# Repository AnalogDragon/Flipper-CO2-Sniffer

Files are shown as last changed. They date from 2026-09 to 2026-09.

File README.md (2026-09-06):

[简体中文](README-zh.md)

# CO2 Sniffer

CO2 Sniffer is a BMP388 + SCD30 environmental monitor for the Flipper Zero. Plug
the board into the GPIO header and open the app to view CO2, temperature,
humidity, pressure and estimated altitude. Readings can also be saved to the
microSD card or sent to a computer over USB.
The software project in `SW/` was developed by OpenAI Codex.

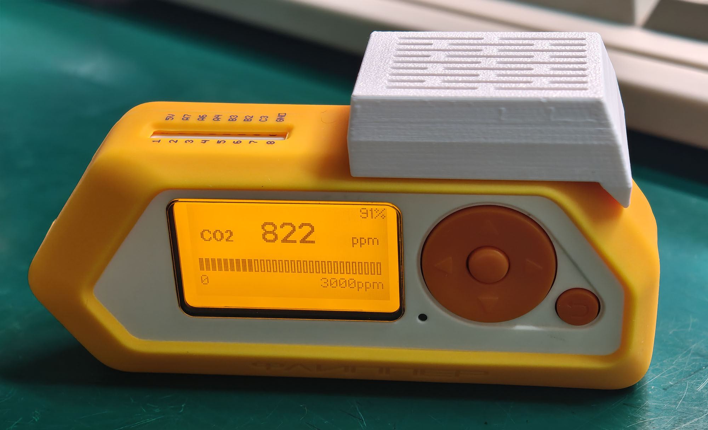
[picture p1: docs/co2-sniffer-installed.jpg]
CO2 Sniffer running on a Flipper Zero


## Main features

- Measures CO2, temperature, humidity and pressure, and estimates altitude from
  the pressure reading.
- Offers several live dashboard layouts and history graphs for all five values.
- Saves readings to CSV at a chosen interval and duration, or sends them to a
  computer over USB.
- Continues with the remaining sensor if one becomes unavailable and reconnects
  it automatically when possible.

To keep startup transients out of the trend, history graphs omit the first 10
seconds after the app starts or the SCD30 reconnects.

## Controls

Button functions change with the current screen. All actions below are short
presses unless marked as a hold.

| Current screen | Input | Function |
| --- | ----- | --- |
| Dashboard | **LEFT** | Open **Data Recording** |
| Dashboard | **RIGHT** | Open the first history graph |
| History graph | **LEFT / RIGHT** | Show the previous / next graph; return to the dashboard at either end |
| Dashboard | **UP / DOWN** | Change the dashboard layout |
| History graph | **UP / DOWN** | Change the graph time scale |
| Dashboard / history graph | **BACK** | Open the clear-history prompt; press **OK** to clear or **BACK** to cancel |
| Data Recording | **UP / DOWN** | Select the interval, length or **Start** field |
| Data Recording | **OK** | Change the selected setting; start when **Start** is selected, or stop while recording |
| Changing a recording setting | **LEFT / RIGHT** | Choose the required value |
| Changing a recording setting / Data Recording | **BACK** | Finish the current change; when not changing a setting, return to the dashboard |
| SCD30 settings | **UP / DOWN**, **OK** | Choose a setting and change it, or open manual calibration |
| Manual-calibration input | **LEFT / RIGHT**, **UP / DOWN** | Select and adjust a digit; press **OK** to review the value |

The following functions require a button hold:

| Where | Input | Function |
| ----- | ----- | --- |
| Data Recording, while not changing a setting | Hold **LEFT** for 2 seconds | Open SCD30 settings |
| While reviewing a manual-calibration value | Hold **OK** for 2 seconds | Start calibration after the progress bar completes |
| When no calibration or exit prompt is shown | Hold **OK** | Turn the always-on backlight on or off |
| Any page | Hold **BACK** | Open the exit prompt; press **OK** to exit or **BACK** to cancel |

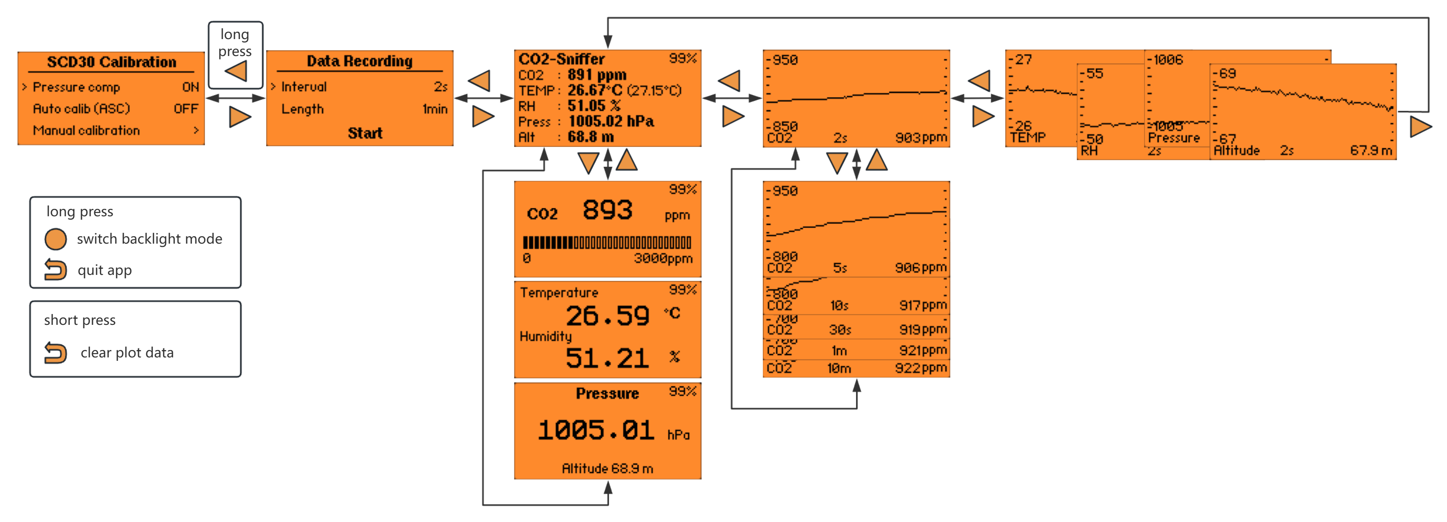
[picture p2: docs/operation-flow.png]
CO2 Sniffer page navigation and controls flowchart


## Data recording

Data recording is useful for tracking environmental changes over time. Press
**LEFT** from the dashboard to open **Data Recording**, choose the interval and
recording length, then select **Start**. Recording ends automatically at the
chosen time. For a continuous recording, or to stop early, press **OK**.

| Setting | Choices |
| --- | --- |
| Interval | 2 s, 5 s, 10 s, 30 s, 1 min |
| Length | 1 min, 5 min, 10 min, 30 min, 1 h, 2 h, 8 h, 24 h, continuous |

Files are saved in `/ext/co2_sniffer/` on the microSD card. Each filename
includes the start time, interval and recording length. Every row contains the
time, elapsed recording time and available sensor readings; values from a
temporarily unavailable sensor are left empty. A blinking `REC` badge means
recording is active. If `SD!` appears, check that the microSD card is available
and writable.

## SCD30 settings and calibration

From **Data Recording**, hold **LEFT** for 2 seconds to open **SCD30
Calibration**. It provides two everyday settings:

- **Pressure comp** uses the current pressure measured by the BMP388 to improve
  SCD30 measurement accuracy.
- **Auto calib (ASC)** lets the SCD30 adjust its baseline during long-term use.

Pressure compensation is on and ASC is off by default. The app remembers later
changes and uses them again at the next startup.

### Manual calibration

Manual calibration is recommended only when the reading has a clear offset and
a reliable CO2 reference concentration is available. Do not treat outdoor air
as an exact 400 ppm reference.

Before calibration, leave the sensor running in a stable reference environment
for at least two minutes and keep faces away from it. Select **Manual
calibration**, enter the actual reference concentration (`0400–2000 ppm`), and
press **OK** to review it. Hold **OK** for 2 seconds; calibration starts only
after the progress bar completes, using the value entered as its reference.

## Hardware

The board connects to the Flipper GPIO port through a 2.54 mm 1×10 pin header
and carries the following sensors:

| Device | Role | I2C address |
| --- | ---- | --- |
| Sensirion SCD30 | CO2, temperature, humidity | 0x61 |
| Bosch BMP388 | temperature, pressure | 0x76 |

I2C runs on GPIO C0 (SCL) / C1 (SDA), and the board is powered from the
Flipper's 3V3/5V pins. KiCad schematic and PCB design sources are in `HW/`.

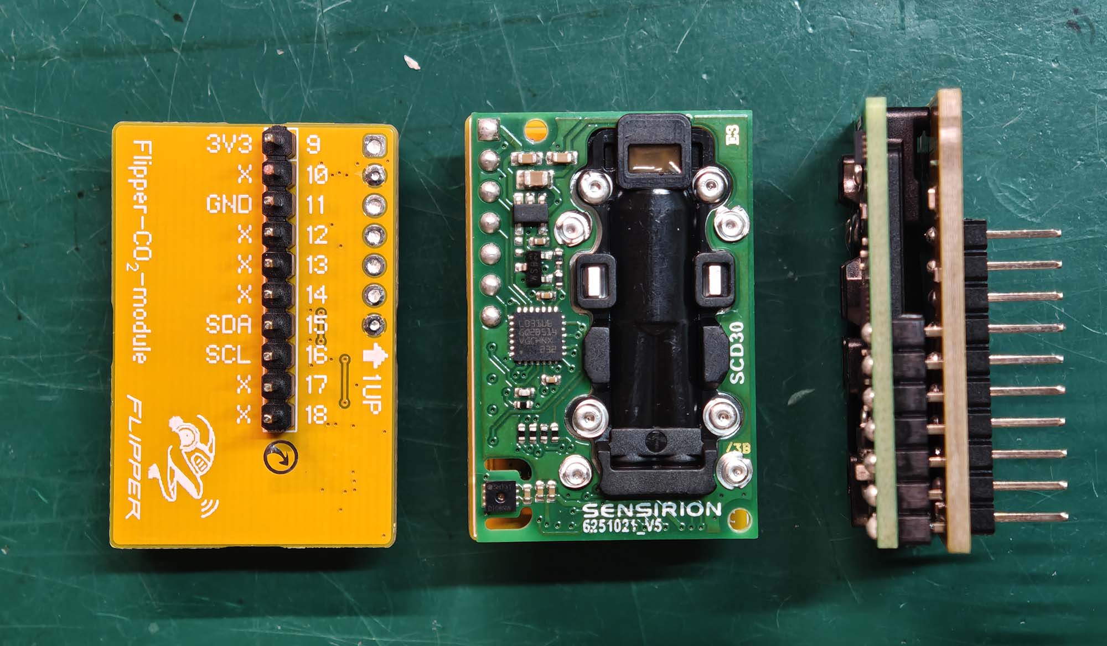
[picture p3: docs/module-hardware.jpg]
CO2 Sniffer module hardware


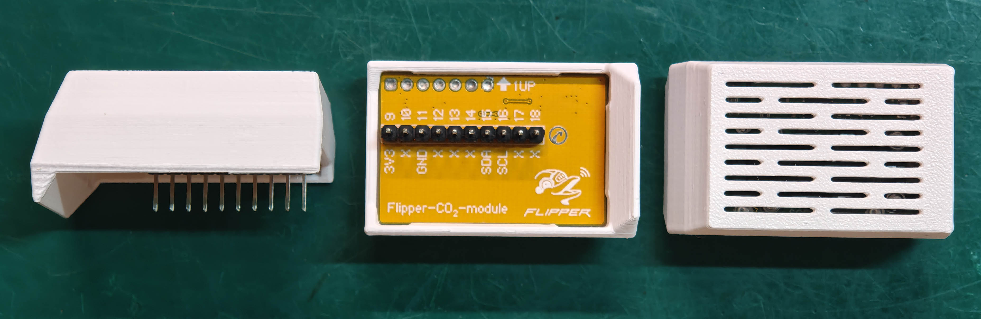
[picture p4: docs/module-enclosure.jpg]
CO2 Sniffer module enclosure from multiple angles


## Fault handling

If one sensor is temporarily disconnected, its readings are shown as
unavailable while the other sensor continues to work. The app attempts to
restore the connection automatically. If the screen reports that the I2C bus
cannot be recovered, exit the app and restart the Flipper as instructed.

## Layout

- `HW/` — KiCad schematic and PCB design sources.
- `SW/` — Flipper app sources.
- `3d/` — Printable enclosure files: a 3MF with Bambu Lab settings and the original STEP model.
- `PROTOCOL.md` — full USB CDC serial protocol documentation.
- `README-zh.md` — this document in Chinese.

## License

GPL-3.0, see [LICENSE](LICENSE).

## USB data output

To receive live readings on a computer, connect the Flipper over USB and select
the second virtual COM port detected by the system. The first port is reserved
for the Flipper CLI. Measurements use a binary frame format; see
**[PROTOCOL.md](PROTOCOL.md)** for the complete frame format and parsing details.

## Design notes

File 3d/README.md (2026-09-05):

[简体中文](README-zh.md)

# 3D Enclosure

These are the printable 3D enclosure files. `shell01.3mf` includes Bambu Lab print settings, while `shell02.STEP` is the original model.

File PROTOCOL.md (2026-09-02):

[简体中文](PROTOCOL-zh.md)

# CO2 Sniffer — USB CDC Serial Protocol

The Flipper app (`SW/co2_sniffer.c`) reads the SCD30 (CO2, temperature, humidity)
and BMP388 (temperature, pressure) sensors and streams a framed binary report to a
PC over USB CDC (virtual COM port). This document describes that stream.

## 1. Transport

- **USB mode:** the app switches the Flipper to the dual CDC configuration
  (`usb_cdc_dual`) and transmits on **interface 1** — on the PC this is the
  **second** virtual COM port. The first COM port is the Flipper CLI console.
- **Baud rate:** irrelevant. CDC is a virtual serial port; the Flipper sends
  at full USB speed and the host-side baud setting is ignored.
- **Flow control:** none. `furi_hal_cdc_send` is non-blocking — if the endpoint
  is busy (host not reading fast enough) the frame is **silently dropped**.
  There is no retry, no buffering beyond the USB endpoint.
- **Host-open detection:** the app treats the port as "open" when DTR is
  asserted (shown as `USB:TX` on the screen; `USB:wait` means no host).
- **Rate:** one frame every **333 ms** (`CO2_TICK_MS`), continuously, for as
  long as the app runs.
- **On exit** the app restores the USB mode that was active before it started.

## 2. Frame format

Every frame is **19 bytes**, big-endian payload, CRC appended little-endian:

| Offset | Size | Field | Encoding |
| --- | ---- | ----- | --- |
| 0 | 4 | Header | `DE AD FF 09` (CH552 VID `0xDEAD` + PID `0xFF09`) |
| 4 | 1 | Payload length | Always `0x0C` (12) |
| 5 | 2 | CO2 (SCD30) | uint16, **ppm**, big-endian |
| 7 | 2 | Temperature (SCD30) | int16, **°C × 100**, big-endian |
| 9 | 2 | Humidity (SCD30) | uint16, **%RH × 100**, big-endian |
| 11 | 2 | Temperature (BMP388) | int16, **°C × 100**, big-endian |
| 13 | 4 | Pressure (BMP388) | uint32, **Pa**, big-endian |
| 17 | 2 | CRC16 | Modbus CRC over bytes 0..16, **little-endian** |

Total: 4 + 1 + 12 + 2 = 19 bytes.

Decoding:

```
co2_ppm     = uint16_be(payload[0:2])
t_scd_c     = int16_be(payload[2:4])  / 100.0
rh_scd_pct  = uint16_be(payload[4:6]) / 100.0
t_bmp_c     = int16_be(payload[6:8])  / 100.0
p_bmp_pa    = uint32_be(payload[8:12])
```

### Sensor failure sentinels

The app re-initializes a failing sensor on every tick and keeps streaming
regardless. A failed sensor reports its fields as all-`0xFF`:

- SCD30 failed → bytes 5..10 = `FF FF FF FF FF FF`
  (CO2 `0xFFFF`, temperature `0xFFFF`, humidity `0xFFFF`)
- BMP388 failed → bytes 11..16 = `FF FF FF FF FF FF`
  (temperature `0xFFFF`, pressure `0xFFFFFFFF`)

Treat these as **"sensor error"**, not as values: `0xFFFF` temperature would
otherwise decode as −0.01 °C, `0xFFFF` humidity as 655.35 %RH.

## 3. CRC16

Modbus CRC16 over the first 17 bytes (header + length + payload):

- Polynomial: `0xA001` (reflected `0x8005`)
- Initial value: `0xFFFF`, no final XOR
- LSB-first (reflected)
- Stored little-endian (low byte at offset 17, high byte at offset 18)

Reference implementations:

```c
/* Modbus CRC16: poly 0xA001, init 0xFFFF, LSB first */
uint16_t crc16_modbus(const uint8_t* data, size_t len) {
    uint16_t crc = 0xFFFF;
    for(size_t i = 0; i < len; i++) {
        crc ^= data[i];
        for(uint8_t b = 0; b < 8; b++)
            crc = (crc & 1) ? (crc >> 1) ^ 0xA001 : crc >> 1;
    }
    return crc;
}
```

```python
def crc16_modbus(data: bytes) -> int:
    crc = 0xFFFF
    for b in data:
        crc ^= b
        for _ in range(8):
            crc = (crc >> 1) ^ 0xA001 if crc & 1 else crc >> 1
    return crc
```

Check: `crc16_modbus(frame[:17])` must equal `frame[17] | frame[18] << 8`, and
`crc16_modbus(frame) == 0` for a complete valid frame.

## 4. Example frame

| Value | Encoding |
| ----- | --- |
| CO2 = 512 ppm | `02 00` |
| SCD30 T = 24.55 °C | `09 97` |
| SCD30 RH = 43.20 %RH | `10 E0` |
| BMP388 T = 24.62 °C | `09 9E` |
| BMP388 P = 100123 Pa | `00 01 87 1B` |

```
DE AD FF 09 0C 02 00 09 97 10 E0 09 9E 00 01 87 1B CA E0
└ header ┘ └len┘ └────────── payload (12) ──────────┘ └ CRC16 LE
```

CRC16 over bytes 0..16 = `0xE0CA`, stored little-endian as `CA E0`.

## 5. Parsing the stream

The stream is a continuous byte pipe with no idle marker. To synchronize:

1. Scan for the header `DE AD FF 09`.
2. Take the byte after the header as length; expect `0x0C`.
3. Take `1 + len + 2` more bytes and verify the CRC over `header + length + payload`
   (`crc16_modbus(frame[:17]) == crc_le`). Reject and rescan on mismatch.
4. An alternative is to chunk by 19 bytes once aligned — a valid CRC per chunk
   keeps the alignment honest.

Note that frames can be dropped by the Flipper when the host is not reading, so
a parser must never assume uninterrupted sequence numbers (there are none).

## 6. Sampling and update rates

The frame cadence (333 ms) is **faster** than the sensor update rates:

- **SCD30:** measurement interval is set to **2 s** at init, so CO2, SCD30
  temperature and humidity values change every ~2 s (every 6th frame) and
  repeat in between. ASC (automatic self-calibration) is disabled at init.
- **BMP388:** configured for 50 Hz output (OSR ×32/×32, normal mode) and is
  read on every 333 ms tick; its temperature/pressure are fresh in every frame.
- **Pressure compensation:** the app feeds the SCD30 an ambient pressure
  (mbar) derived from the BMP388 pressure low-pass filtered with
  `P_FIL = 0.95·P_FIL + 0.05·P_LIN`. When the filtered pressure changes and is
  within 700..1200 mbar, the SCD30 measurement is restarted with the new
  pressure. Rounding is `(uint16_t)((P_FIL + 0.5) / 100)`.
- **Re-init:** pressing **OK** on the Flipper re-initializes both sensors
  (soft reset; the original CH552 board power-cycled them instead).

## 7. History note

The original CH552 sniffer board streamed the same report layout as an HID
report. FAPs cannot register custom HID descriptors, so this port transmits
the identical frame over CDC. The layout is byte-compatible with the CH552 HID
report, which is why the header encodes the CH552's VID/PID.

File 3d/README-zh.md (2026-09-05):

[English](README.md)

# 3D 外壳

这里是可直接打印的 3D 外壳文件。`shell01.3mf` 包含拓竹打印配置，`shell02.STEP` 是原始模型文件。

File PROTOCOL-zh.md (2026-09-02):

[English](PROTOCOL.md)

# CO2 Sniffer — USB CDC 串口协议

Flipper 应用（`SW/co2_sniffer.c`）读取 SCD30（CO2、温度、湿度）与 BMP388
（温度、气压）传感器，并通过 USB CDC（虚拟串口）向 PC 流式发送二进制帧数据。
本文档描述这个数据流。

## 1. 传输层

- **USB 模式：**应用把 Flipper 切换到双 CDC 配置（`usb_cdc_dual`），并在
  **接口 1** 上发送数据——PC 上是**第二个**虚拟串口。第一个串口是 Flipper
  CLI 控制台。
- **波特率：**无意义。CDC 是虚拟串口；Flipper 以全速 USB 发送，上位机端设置
  的波特率会被忽略。
- **流控：**无。`furi_hal_cdc_send` 非阻塞——端点忙（上位机读取不及时）时该帧
  被**静默丢弃**。没有重传，也没有超出 USB 端点的缓冲。
- **主机打开检测：**当 DTR 置位时应用认为端口"已打开"（屏幕显示 `USB:TX`；
  `USB:wait` 表示没有主机）。
- **速率：**应用运行期间每 **333 ms**（`CO2_TICK_MS`）连续发送一帧。
- **退出时**应用恢复启动前的 USB 模式。

## 2. 帧格式

每帧 **19 字节**，载荷大端序，CRC 以小端序追加：

| 偏移 | 大小 | 字段 | 编码 |
| ---- | ---- | ---- | ---- |
| 0 | 4 | 帧头 | `DE AD FF 09`（CH552 VID `0xDEAD` + PID `0xFF09`） |
| 4 | 1 | 载荷长度 | 固定 `0x0C`（12） |
| 5 | 2 | CO2（SCD30） | uint16，**ppm**，大端序 |
| 7 | 2 | 温度（SCD30） | int16，**°C × 100**，大端序 |
| 9 | 2 | 湿度（SCD30） | uint16，**%RH × 100**，大端序 |
| 11 | 2 | 温度（BMP388） | int16，**°C × 100**，大端序 |
| 13 | 4 | 气压（BMP388） | uint32，**Pa**，大端序 |
| 17 | 2 | CRC16 | Modbus CRC，对字节 0..16 计算，**小端序** |

总计：4 + 1 + 12 + 2 = 19 字节。

解码公式：

```
co2_ppm     = uint16_be(payload[0:2])
t_scd_c     = int16_be(payload[2:4])  / 100.0
rh_scd_pct  = uint16_be(payload[4:6]) / 100.0
t_bmp_c     = int16_be(payload[6:8])  / 100.0
p_bmp_pa    = uint32_be(payload[8:12])
```

### 传感器故障哨兵值

应用每个周期都会重新初始化出故障的传感器，并保持数据流不断。故障传感器的
字段全部为 `0xFF`：

- SCD30 故障 → 字节 5..10 = `FF FF FF FF FF FF`
  （CO2 `0xFFFF`、温度 `0xFFFF`、湿度 `0xFFFF`）
- BMP388 故障 → 字节 11..16 = `FF FF FF FF FF FF`
  （温度 `0xFFFF`、气压 `0xFFFFFFFF`）

请把这些值当作**"传感器错误"**而不是数值：`0xFFFF` 温度会被解码为 −0.01 °C，
`0xFFFF` 湿度会被解码为 655.35 %RH。

## 3. CRC16

对前 17 个字节（帧头 + 长度 + 载荷）计算 Modbus CRC16：

- 多项式：`0xA001`（`0x8005` 的反射形式）
- 初值：`0xFFFF`，无最终异或
- LSB 优先（反射）
- 以小端序存储（低字节在偏移 17，高字节在偏移 18）

参考实现：

```c
/* Modbus CRC16: poly 0xA001, init 0xFFFF, LSB first */
uint16_t crc16_modbus(const uint8_t* data, size_t len) {
    uint16_t crc = 0xFFFF;
    for(size_t i = 0; i < len; i++) {
        crc ^= data[i];
        for(uint8_t b = 0; b < 8; b++)
            crc = (crc & 1) ? (crc >> 1) ^ 0xA001 : crc >> 1;
    }
    return crc;
}
```

```python
def crc16_modbus(data: bytes) -> int:
    crc = 0xFFFF
    for b in data:
        crc ^= b
        for _ in range(8):
            crc = (crc >> 1) ^ 0xA001 if crc & 1 else crc >> 1
    return crc
```

校验方法：`crc16_modbus(frame[:17])` 必须等于 `frame[17] | frame[18] << 8`，
且对完整有效帧 `crc16_modbus(frame) == 0`。

## 4. 示例帧

| 数值 | 编码 |
| ---- | ---- |
| CO2 = 512 ppm | `02 00` |
| SCD30 温度 = 24.55 °C | `09 97` |
| SCD30 湿度 = 43.20 %RH | `10 E0` |
| BMP388 温度 = 24.62 °C | `09 9E` |
| BMP388 气压 = 100123 Pa | `00 01 87 1B` |

```
DE AD FF 09 0C 02 00 09 97 10 E0 09 9E 00 01 87 1B CA E0
└ 帧头 ┘ └长度┘ └────────── 载荷 (12) ──────────┘ └ CRC16 LE
```

字节 0..16 的 CRC16 = `0xE0CA`，以小端序存储为 `CA E0`。

## 5. 解析数据流

数据流是连续的字节流，没有空闲标记。同步方法：

1. 扫描帧头 `DE AD FF 09`。
2. 帧头后的字节是长度；应为 `0x0C`。
3. 再取 `1 + len + 2` 个字节，对 `帧头 + 长度 + 载荷` 校验 CRC
   （`crc16_modbus(frame[:17]) == crc_le`）。不匹配则丢弃并重新扫描。
4. 对齐后也可以按 19 字节分块——每块 CRC 有效即可保持对齐不被破坏。

注意：上位机未读取时 Flipper 会丢弃帧，所以解析器绝不能假设帧序号连续
（协议里本来也没有序号）。

## 6. 采样与更新速率

帧的发送周期（333 ms）**快于**传感器的更新速率：

- **SCD30：**初始化时测量间隔设为 **2 s**，因此 CO2、SCD30 温度与湿度约每
  2 s 更新一次（每 6 帧），期间数值重复。初始化时关闭了 ASC（自动自校准）。
- **BMP388：**配置为 50 Hz 输出（OSR ×32/×32，normal 模式），每个 333 ms 周期
  都读取；其温度/气压在每一帧中都是新值。
- **气压补偿：**应用根据 BMP388 气压的低通滤波值
  （`P_FIL = 0.95·P_FIL + 0.05·P_LIN`）向 SCD30 提供环境气压（mbar）。当滤波
  气压发生变化且处于 700..1200 mbar 范围内时，用新气压重启 SCD30 测量。取整
  方式为 `(uint16_t)((P_FIL + 0.5) / 100)`。
- **重新初始化：**在 Flipper 上按 **OK** 会重新初始化两个传感器（软复位；
  原来的 CH552 板是直接断电重启）。

## 7. 历史说明

原来的 CH552 嗅探板以 HID 报告的形式发送相同布局的数据。FAP 无法注册自定义
HID 描述符，所以本移植版通过 CDC 发送完全相同的帧。布局与 CH552 的 HID 报告
字节兼容，这也是帧头编码 CH552 VID/PID 的原因。

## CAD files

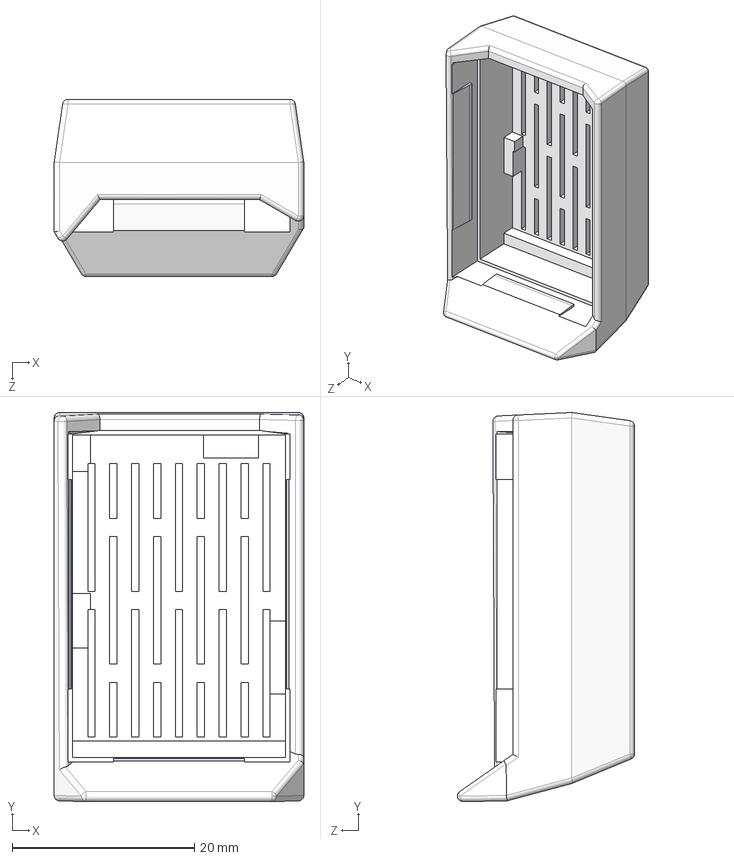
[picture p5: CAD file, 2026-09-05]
3d/shell02.STEP
27.4 x 42.7 x 19.4 mm

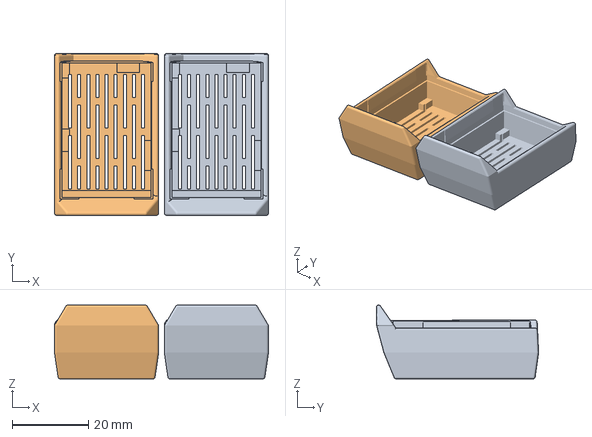
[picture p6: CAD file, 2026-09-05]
3d/shell01.3mf
56.3 x 42.7 x 19.4 mm
shell02.STEP x 2

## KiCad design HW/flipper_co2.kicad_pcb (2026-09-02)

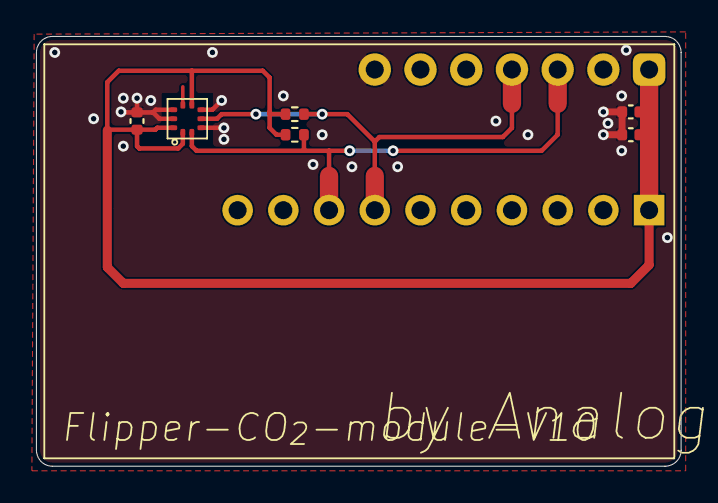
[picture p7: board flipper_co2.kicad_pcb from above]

Board: 2 copper layers, 35.8 x 23.9 mm, 8 parts (1 on the bottom side), 4 nets.

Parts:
C1: 106/6.3V; C_0402_1005Metric
C2, C13: 104/50V; C_0402_1005Metric
J2: 2.54mm pinheader L=7.5mm; PinHeader_1x10_P2.54mm_Vertical
R1, R2: 4.7K; R_0402_1005Metric
U1: SCD30+2.54mm pinheader L=7.5mm; SCD30
U5: BMP388; LGA10-2x2-BMP388

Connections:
+3V3: C1.1, C2.1, C13.1, J2.1, R1.2, R2.2, U1.1 (VCC), U5.1 (VDDIO), U5.6 (CSB/I_{2}C_{EN}), U5.10 (VDD)
GND: C1.2, C2.2, C13.2, J2.3, U1.2 (GND), U1.7 (SEL), U5.3 (VSS), U5.5 (SDO/AD0), U5.8 (VSS), U5.9 (VSS)
IIC_SCL: J2.8, R1.1, U1.3 (SCL/TX), U5.2 (SCK)
IIC_SDA: J2.7, R2.1, U1.4 (SDA/RX), U5.4 (SDI/SDA)

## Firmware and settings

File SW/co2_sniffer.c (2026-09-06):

#include <furi.h>
#include <furi_hal_power.h>
#include <furi_hal_rtc.h>
#include <gui/gui.h>
#include <input/input.h>
#include <math.h>
#include <notification/notification_messages.h>
#include <storage/storage.h>
#include <stdio.h>
#include <string.h>

#include "co2_sniffer_i2c.h"
#include "co2_sniffer_bmp388.h"
#include "co2_sniffer_scd30.h"
#include "co2_sniffer_usb.h"

/* Serial frame streamed over CDC (big-endian):
 * [0..3]   header 0xDE 0xAD 0xFF 0x09
 * [4]      payload length in bytes
 * [5..16]  CO2, SCD30 temperature/RH, BMP388 temperature/pressure
 * [17..18] Modbus CRC16, little-endian. */
#define CO2_FRAME_HDR 4
#define CO2_FRAME_LEN 1
#define CO2_FRAME_PAYLOAD 12
#define CO2_FRAME_CRC 2
#define CO2_FRAME_SIZE (CO2_FRAME_HDR + CO2_FRAME_LEN + CO2_FRAME_PAYLOAD + CO2_FRAME_CRC)

#define CO2_TICK_MS 333
#define CO2_DATA_PAGE_COUNT 6
#define CO2_RECORD_PAGE CO2_DATA_PAGE_COUNT
#define CO2_SCD_SETTINGS_PAGE (CO2_RECORD_PAGE + 1)
#define CO2_SCD_CAL_INFO_PAGE (CO2_RECORD_PAGE + 2)
#define CO2_SCD_CAL_PAGE (CO2_RECORD_PAGE + 3)
#define CO2_STYLE_COUNT 4
#define CO2_TIME_SCALE_COUNT 6
#define CO2_HISTORY_POINTS 128
#define CO2_METRIC_COUNT 5
#define CO2_BMP_WARMUP_MS 10000
#define CO2_SCD_WARMUP_MS 10000
#define CO2_ALTITUDE_FILTER_ALPHA 0.2f
#define CO2_RECORD_INTERVAL_COUNT 5
#define CO2_RECORD_DURATION_COUNT 9
#define CO2_RECORD_CONTINUOUS 8
#define CO2_RECORD_DIRECTORY EXT_PATH("co2_sniffer")
#define CO2_SETTINGS_PATH CO2_RECORD_DIRECTORY "/settings.bin"
#define CO2_HOLD_ACTION_MS 2000
#define CO2_FRC_DEFAULT_PPM 420

typedef enum {
    Co2MetricCo2,
    Co2MetricTemperature,
    Co2MetricHumidity,
    Co2MetricPressure,
    Co2MetricAltitude,
} Co2Metric;

typedef enum {
    Co2FrcResultNone,
    Co2FrcResultSuccess,
    Co2FrcResultFailure,
    Co2FrcResultInvalid,
} Co2FrcResult;

static const uint32_t co2_time_scale_ms[CO2_TIME_SCALE_COUNT] = {
    2000,
    5000,
    10000,
    30000,
    60000,
    600000,
};

static const char* const co2_time_scale_name[CO2_TIME_SCALE_COUNT] = {
    "2s",
    "5s",
    "10s",
    "30s",
    "1m",
    "10m",
};

static const uint32_t co2_record_interval_ms[CO2_RECORD_INTERVAL_COUNT] = {
    2000,
    5000,
    10000,
    30000,
    60000,
};

static const char* const co2_record_interval_name[CO2_RECORD_INTERVAL_COUNT] = {
    "2s",
    "5s",
    "10s",
    "30s",
    "1min",
};

static const uint32_t co2_record_duration_ms[CO2_RECORD_DURATION_COUNT - 1] = {
    60000,
    300000,
    600000,
    1800000,
    3600000,
    7200000,
    28800000,
    86400000,
};

static const char* const co2_record_duration_name[CO2_RECORD_DURATION_COUNT] = {
    "1min",
    "5min",
    "10min",
    "30min",
    "1h",
    "2h",
    "8h",
    "24h",
    "continuous",
};

static const NotificationSequence co2_backlight_enable_sequence = {
    &message_display_backlight_off,
    &message_delay_100,
    &message_display_backlight_on,
    &message_delay_100,
    &message_display_backlight_off,
    &message_delay_100,
    &message_display_backlight_on,
    &message_display_backlight_enforce_on,
    NULL,
};

static const NotificationSequence co2_backlight_disable_sequence = {
    &message_display_backlight_enforce_auto,
    &message_display_backlight_off,
    &message_delay_500,
    &message_display_backlight_on,
    NULL,
};

typedef struct {
    Co2Bmp388 bmp;
    Co2Scd30 scd;

    FuriMutex* mutex;
    bool bmp_ok;
    bool scd_ok;
    float T_LIN;
    float P_LIN;
    float altitude;
    float CO2_PPM;
    float T_SCD;
    float R_SCD;
    bool usb_active;
    bool host_open;
    uint32_t frames_sent;

    bool home_done;
    uint8_t home_category;
    uint32_t home_deadline_ms;
    uint8_t page;
    uint8_t style;
    uint8_t time_scale;
    bool clear_confirm;
    bool exit_confirm;
    bool history_reset_requested;
    bool backlight_always_on;

    uint8_t record_interval;
    uint8_t record_duration;
    uint8_t record_cursor;
    bool record_editing;
    bool record_start_requested;
    bool record_stop_requested;
    bool recording;
    bool record_error;
    bool i2c_fatal;

    bool scd_pressure_compensation;
    bool scd_asc_enabled;
    bool scd_settings_save_requested;
    bool scd_settings_apply_requested;
    bool scd_settings_save_error;
    uint8_t scd_settings_cursor;

    uint16_t frc_reference_ppm;
    uint8_t frc_digit_cursor;
    uint32_t frc_started_at;
    bool frc_confirm;
    bool frc_requested;
    bool frc_pending;
    Co2FrcResult frc_result;

    bool left_hold_active;
    bool left_hold_consumed;
    uint32_t left_hold_started_at;
    bool ok_hold_active;
    bool ok_hold_consumed;
    uint32_t ok_hold_started_at;

    /* Each time scale has its own 128-point ring. This preserves every graph
     * while keeping the session history below 20 KB. */
    float history[CO2_TIME_SCALE_COUNT][CO2_METRIC_COUNT][CO2_HISTORY_POINTS];
    uint8_t history_valid[CO2_TIME_SCALE_COUNT][CO2_HISTORY_POINTS];
    uint8_t history_head[CO2_TIME_SCALE_COUNT];
    uint8_t history_count[CO2_TIME_SCALE_COUNT];
    int32_t graph_low[CO2_TIME_SCALE_COUNT][CO2_METRIC_COUNT];
    int32_t graph_high[CO2_TIME_SCALE_COUNT][CO2_METRIC_COUNT];
    uint8_t graph_bounds_valid[CO2_TIME_SCALE_COUNT];

    Gui* gui;
    NotificationApp* notifications;
    ViewPort* view_port;
    FuriThread* worker;
    volatile bool running;
} Co2SnifferApp;

static bool co2_time_reached(uint32_t now, uint32_t deadline) {
    return (int32_t)(now - deadline) >= 0;
}

static uint8_t co2_settings_checksum(const uint8_t* data, size_t length) {
    uint8_t checksum = 0xA5;
    for(size_t i = 0; i < length; i++) checksum ^= data[i];
    return checksum;
}

static bool co2_settings_save(Storage* storage, bool pressure_compensation, bool asc_enabled) {
    FS_Error mkdir_error = storage_common_mkdir(storage, CO2_RECORD_DIRECTORY);
    if(mkdir_error != FSE_OK && mkdir_error != FSE_EXIST) return false;

    uint8_t data[8] = {'C', '2', 'S', 'C', 1, 0, 0, 0};
    if(pressure_compensation) data[5] |= 1U;
    if(asc_enabled) data[5] |= 2U;
    data[7] = co2_settings_checksum(data, 7);

    File* file = storage_file_alloc(storage);
    bool opened = storage_file_open(file, CO2_SETTINGS_PATH, FSAM_WRITE, FSOM_CREATE_ALWAYS);
    bool saved = opened && storage_file_write(file, data, sizeof(data)) == sizeof(data) &&
                 storage_file_sync(file);
    storage_file_close(file);
    storage_file_free(file);
    return saved;
}
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

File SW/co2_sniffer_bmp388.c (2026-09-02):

#include "co2_sniffer_bmp388.h"

#include <furi.h>

#include "co2_sniffer_i2c.h"

#define BMP_REG_CMD 0x7E /* soft reset */
#define BMP_REG_PWR_CTRL 0x1B
#define BMP_REG_OSR 0x1C
#define BMP_REG_ODR 0x1D
#define BMP_REG_ERR 0x02 /* ERR_REG; read starts here, data follows 0x03..0x09 */
#define BMP_REG_NVM_START 0x31 /* 21 bytes of calibration data */

/* NVM calibration parameters, pre-scaled. Ported verbatim from the CH552
 * firmware (GPIO.c). All math there ran in 32-bit float (C51 "double" is
 * float32), so float is used here as well - this exact scheme was verified
 * on hardware. The divisors fold the Bosch reference implementation's
 * power-of-two factors into the parameters, so the formulas below yield
 * plain °C and Pa directly. Do not "fix" it into the Bosch form. */
static float PAR_T1, PAR_T2, PAR_T3;
static float PAR_P1, PAR_P2, PAR_P3, PAR_P4, PAR_P5, PAR_P6;
static float PAR_P7, PAR_P8, PAR_P9, PAR_P10, PAR_P11;

static bool bmp388_nvm_par(void) {
    uint8_t d[21];
    uint8_t reg = BMP_REG_NVM_START;
    if(!co2_i2c_reg_read(CO2_ADDR_BMP388, &reg, 1, d, sizeof(d))) {
        return false;
    }

    uint16_t NVM_T1 = (uint16_t)d[0] | ((uint16_t)d[1] << 8);
    uint16_t NVM_T2 = (uint16_t)d[2] | ((uint16_t)d[3] << 8);
    int8_t NVM_T3 = (int8_t)d[4];

    int16_t NVM_P1 = (int16_t)((uint16_t)d[5] | ((uint16_t)d[6] << 8));
    int16_t NVM_P2 = (int16_t)((uint16_t)d[7] | ((uint16_t)d[8] << 8));
    int8_t NVM_P3 = (int8_t)d[9];
    int8_t NVM_P4 = (int8_t)d[10];
    uint16_t NVM_P5 = (uint16_t)d[11] | ((uint16_t)d[12] << 8);
    uint16_t NVM_P6 = (uint16_t)d[13] | ((uint16_t)d[14] << 8);
    int8_t NVM_P7 = (int8_t)d[15];
    int8_t NVM_P8 = (int8_t)d[16];
    int16_t NVM_P9 = (int16_t)((uint16_t)d[17] | ((uint16_t)d[18] << 8));
    int8_t NVM_P10 = (int8_t)d[19];
    int8_t NVM_P11 = (int8_t)d[20];

    float temp_var;
    temp_var = 0.00390625f;
    PAR_T1 = ((float)NVM_T1 / temp_var);
    temp_var = 1073741824.0f;
    PAR_T2 = ((float)NVM_T2 / temp_var);
    temp_var = 281474976710656.0f;
    PAR_T3 = ((float)NVM_T3 / temp_var);
    temp_var = 1048576.0f;
    PAR_P1 = ((float)(NVM_P1 - (16384)) / temp_var);
    temp_var = 536870912.0f;
    PAR_P2 = ((float)(NVM_P2 - (16384)) / temp_var);
    temp_var = 4294967296.0f;
    PAR_P3 = ((float)NVM_P3 / temp_var);
    temp_var = 137438953472.0f;
    PAR_P4 = ((float)NVM_P4 / temp_var);
    temp_var = 0.125f;
    PAR_P5 = ((float)NVM_P5 / temp_var);
    temp_var = 64.0f;
    PAR_P6 = ((float)NVM_P6 / temp_var);
    temp_var = 256.0f;
    PAR_P7 = ((float)NVM_P7 / temp_var);
    temp_var = 32768.0f;
    PAR_P8 = ((float)NVM_P8 / temp_var);
    temp_var = 281474976710656.0f;
    PAR_P9 = ((float)NVM_P9 / temp_var);
    temp_var = 281474976710656.0f;
    PAR_P10 = ((float)NVM_P10 / temp_var);
    temp_var = 36893488147419103232.0f;
    PAR_P11 = ((float)NVM_P11 / temp_var);

    return true;
}

static void temp_conv(uint32_t raw_temp, float* t_lin) {
    float partial_data1;
    float partial_data2;

    partial_data1 = (float)((float)raw_temp - PAR_T1);
    partial_data2 = (float)(partial_data1 * PAR_T2);

    *t_lin = partial_data2 + (partial_data1 * partial_data1) * PAR_T3;
}

static void press_conv(uint32_t raw_press, float t_lin, float* p_lin) {
    float in_press = raw_press;

    float partial_data1;
    float partial_data2;
    float partial_data3;
    float partial_data4;
    float partial_out1;
    float partial_out2;

    partial_data1 = PAR_P6 * t_lin;
    partial_data2 = PAR_P7 * t_lin * t_lin;
    partial_data3 = PAR_P8 * t_lin * t_lin * t_lin;
    partial_out1 = PAR_P5 + partial_data1 + partial_data2 + partial_data3;
    partial_data1 = PAR_P2 * t_lin;
    partial_data2 = PAR_P3 * t_lin * t_lin;
    partial_data3 = PAR_P4 * t_lin * t_lin * t_lin;
    partial_out2 = raw_press * (PAR_P1 + partial_data1 + partial_data2 + partial_data3);
    partial_data1 = in_press * in_press;
    partial_data2 = PAR_P9 + PAR_P10 * t_lin;
    partial_data3 = partial_data1 * partial_data2;
    partial_data4 = partial_data3 + (in_press * in_press * in_press) * PAR_P11;

    *p_lin = partial_out1 + partial_out2 + partial_data4;
}

static bool bmp388_write_reg(uint8_t reg, uint8_t val) {
    return co2_i2c_reg_write(CO2_ADDR_BMP388, &reg, 1, &val, 1);
}

bool co2_bmp388_init(Co2Bmp388* s) {
    s->fail = true;

    if(!bmp388_write_reg(BMP_REG_CMD, 0xB6)) return false; /* reset */
    furi_delay_ms(20);
    if(!bmp388_write_reg(BMP_REG_OSR, 0x2D)) return false; /* osr_t x32, osr_p x32 */
    if(!bmp388_write_reg(BMP_REG_ODR, 0x05)) return false; /* 50 Hz */
    if(!bmp388_write_reg(BMP_REG_PWR_CTRL, 0x33)) return false; /* normal mode, T+P on */
    furi_delay_ms(10);

    uint8_t err;
    uint8_t reg = BMP_REG_ERR;
    if(!co2_i2c_reg_read(CO2_ADDR_BMP388, &reg, 1, &err, 1)) return false;
    if(err != 0) return false;

    if(!bmp388_nvm_par()) return false;

    s->fail = false;
    return true;
}

bool co2_bmp388_read(Co2Bmp388* s) {
    if(s->fail) return false;

    /* regs: [0]=ERR [1]=STATUS [2..4]=pressure raw LE24 [5..7]=temp raw LE24 */
    uint8_t reg = BMP_REG_ERR;
    uint8_t regs[8];
    if(!co2_i2c_reg_read(CO2_ADDR_BMP388, &reg, 1, regs, sizeof(regs))) {
        s->fail = true;
        return false;
    }
    if(regs[0] != 0) { /* fatal error flag set */
        s->fail = true;
        return false;
    }

    uint32_t raw_p = (uint32_t)regs[2] | ((uint32_t)regs[3] << 8) | ((uint32_t)regs[4] << 16);
    uint32_t raw_t = (uint32_t)regs[5] | ((uint32_t)regs[6] << 8) | ((uint32_t)regs[7] << 16);

    float t_lin;
    float p_lin;
    temp_conv(raw_t, &t_lin);
    press_conv(raw_p, t_lin, &p_lin);

    s->T_LIN = t_lin;
    s->P_LIN = p_lin;
    if(s->P_FIL == 0)
        s->P_FIL = s->P_LIN;
    else
        s->P_FIL = s->P_FIL * 0.95f + s->P_LIN * 0.05f;

    return true;
}
